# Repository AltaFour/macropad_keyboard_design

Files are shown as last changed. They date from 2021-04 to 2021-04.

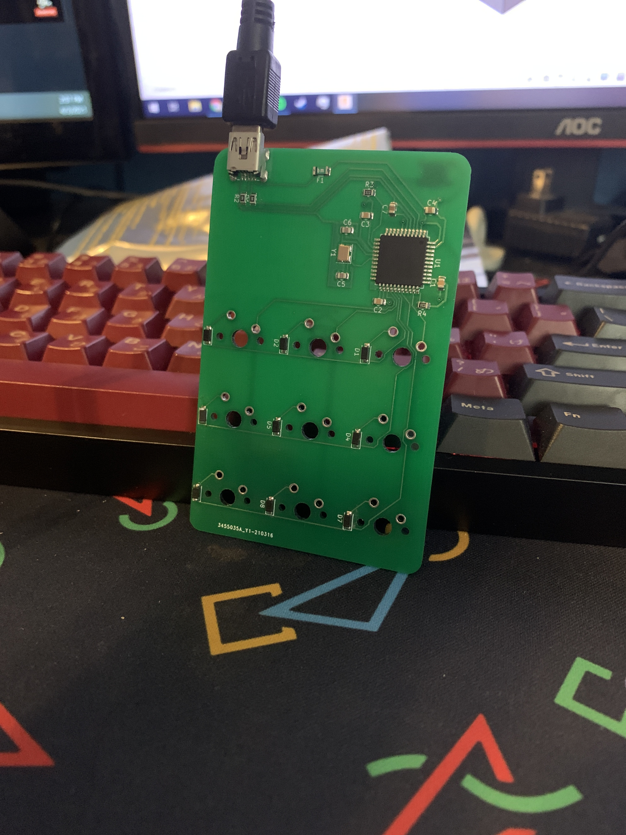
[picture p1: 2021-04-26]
Images/PCB-Assembled.JPG

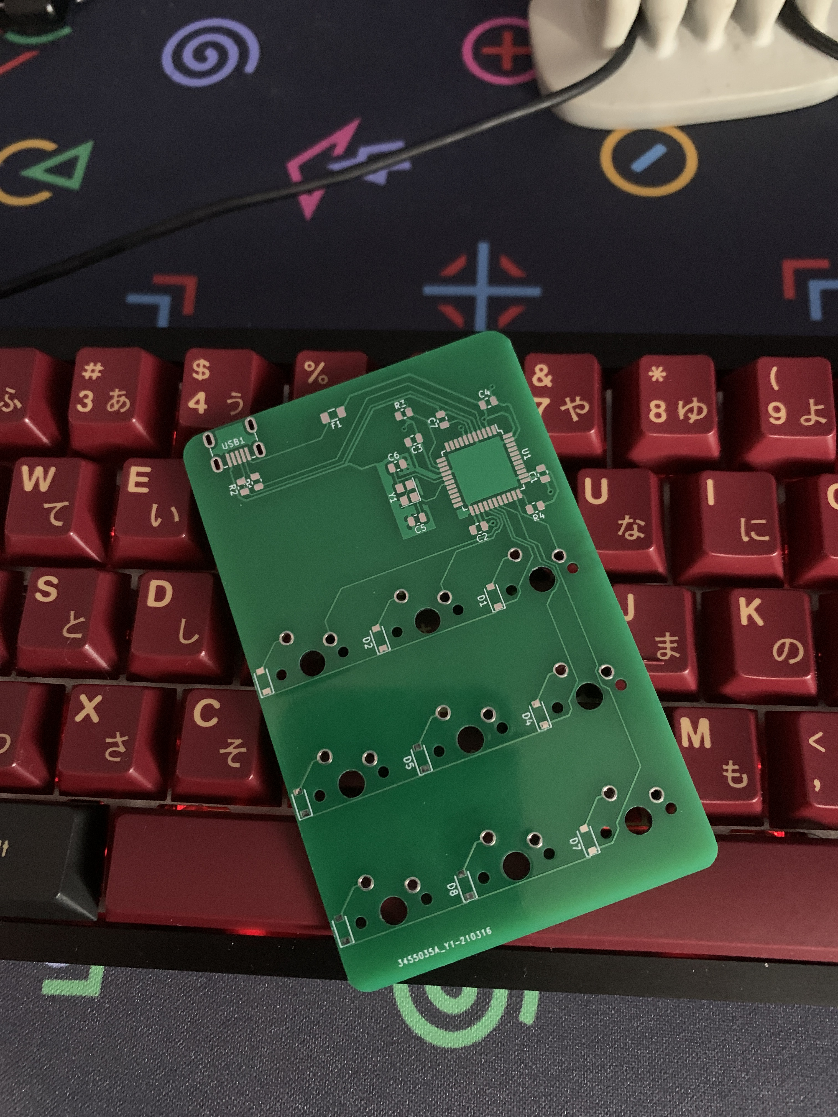
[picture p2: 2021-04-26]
Images/PCB-Back.JPG

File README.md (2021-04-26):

# macropad_keyboard_design
Software Used:
Autodesk Fusion 360 (Cad Software that is free for personal projects)
KiCad (Open Source PCB design software)
Github
Git

Manufacturing:
JLCPCB


This is the manufactured board without the components on it. I took this, solder paste and a aluminuim stencil and assembled the components on the board. I then put it in our toaster over and turned it up to full heat until all of the paste turned silver and metalic meaning that the connection was bridged.


This is a screenshot of the PCB design from KiCad which is a free open source pcb design software. I formatted this and sent it off to JLC PCB and they sent me the boards which are shown above.


This is a picture of the final product. I used SMD soldering to attach all the components. It has been flashed with QMK and works perfectly. I also designed a case that I am going to have 3d printed once we finish building our 3d printer(will attach pictures with case after).

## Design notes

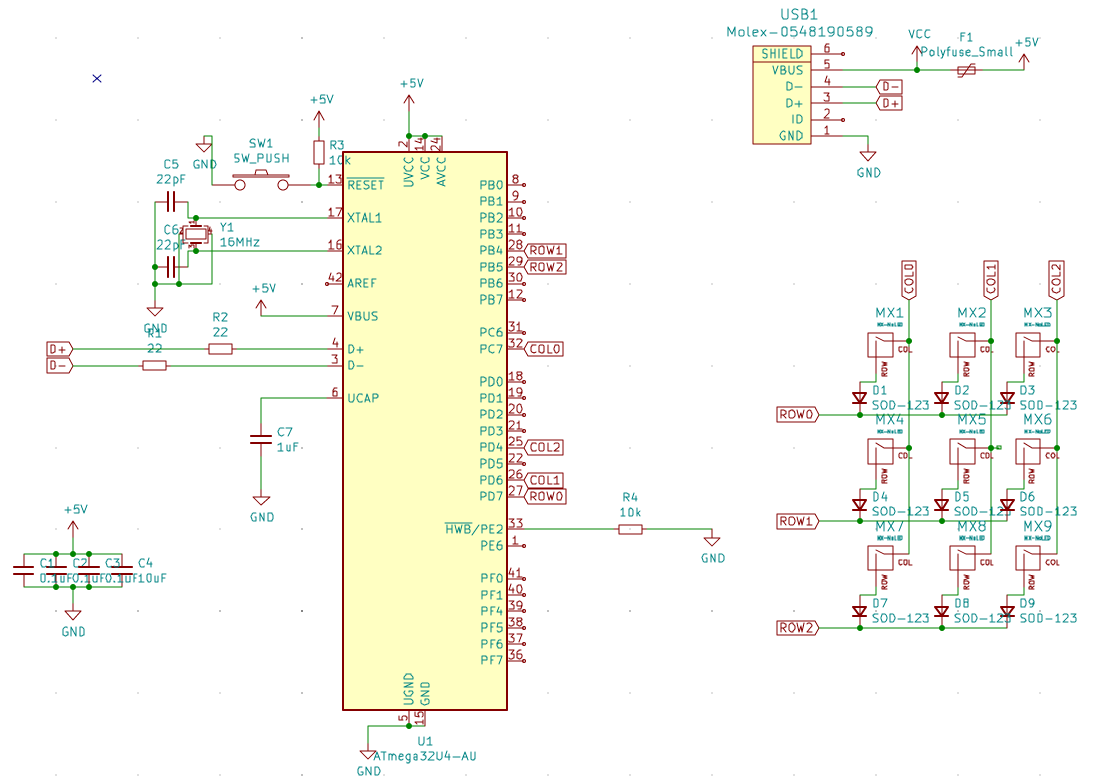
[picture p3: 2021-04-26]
Images/PCB-Schematic.png

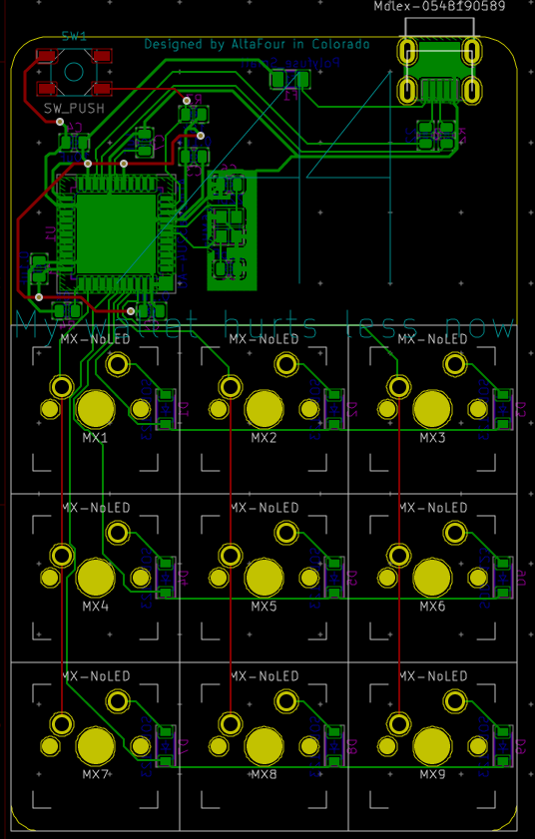
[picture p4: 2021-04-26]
Images/PCB-Layout.png

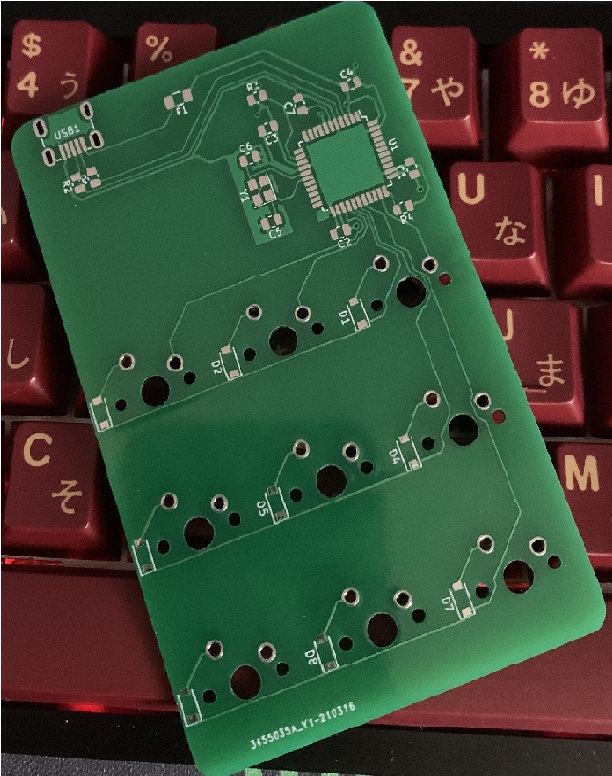
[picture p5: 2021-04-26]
Images/PCB-Back-Small.jpg

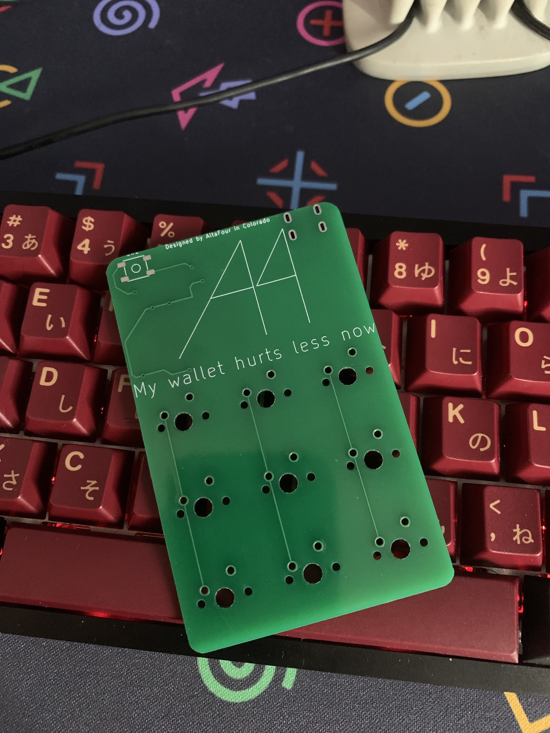
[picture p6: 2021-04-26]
Images/PCB-Front.JPG

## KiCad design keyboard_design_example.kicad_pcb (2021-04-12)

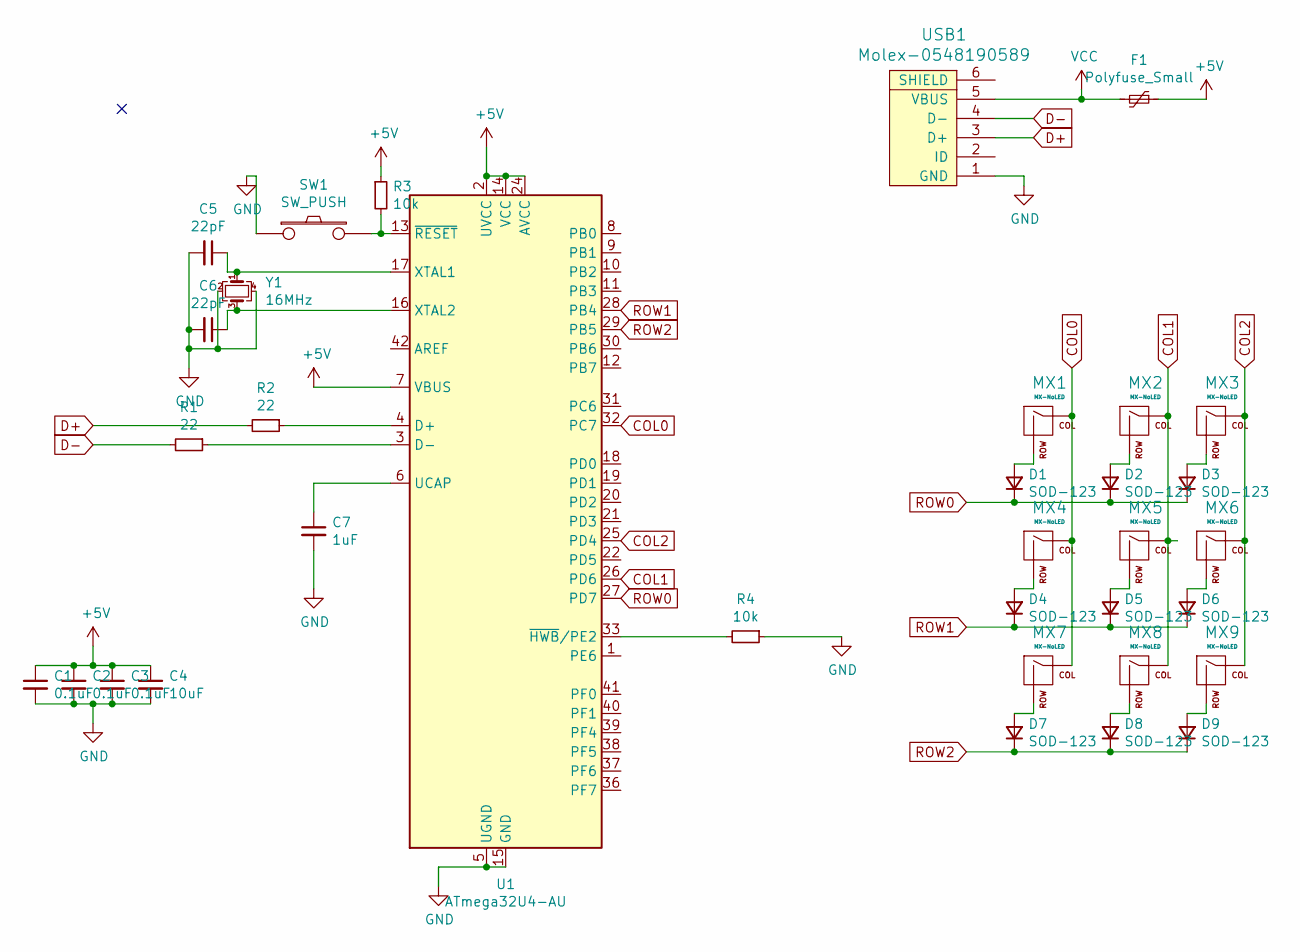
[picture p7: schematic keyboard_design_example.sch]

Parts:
C1, C2, C3: 0.1uF; C_0805_2012Metric
C4: 10uF; C_0805_2012Metric
C5, C6: 22pF; C_0805_2012Metric
C7: 1uF; C_0805_2012Metric
D1, D2, D3, D4, D5, D6, D7, D8, D9: SOD-123; D_SOD-123
F1: Polyfuse_Small; Fuse_1206_3216Metric
MX1, MX2, MX3, MX4, MX5, MX6, MX7, MX8, MX9: MX-NoLED; MXOnly-1U-NoLED
R1, R2: 22; R_0805_2012Metric
R3, R4: 10k; R_0805_2012Metric
SW1: SW_PUSH; SKQG-1155865
U1: ATmega32U4-AU; TQFP-44_10x10mm_P0.8mm
USB1: Molex-0548190589
Y1: 16MHz; Crystal_SMD_3225-4Pin_3.2x2.5mm

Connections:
+5V: C1.1, C2.1, C3.1, C4.1, F1.1, R3.1, U1.2 (UVCC), U1.7 (VBUS), U1.14 (VCC), U1.24 (AVCC), U1.34 (VCC), U1.44 (AVCC)
COL0: MX1.1 (COL), MX4.1 (COL), MX7.1 (COL), U1.32 (PC7)
COL1: MX2.1 (COL), MX5.1 (COL), MX8.1 (COL), U1.26 (PD6)
COL2: MX3.1 (COL), MX6.1 (COL), MX9.1 (COL), U1.25 (PD4)
D+: R2.2, USB1.3 (D+)
D-: R1.2, USB1.4 (D-)
GND: C1.2, C2.2, C3.2, C4.2, C5.2, C6.2, C7.2, R4.1, SW1.1, U1.5 (UGND), U1.15 (GND), U1.23 (GND), U1.35 (GND), U1.43 (GND), USB1.1 (GND), Y1.2, Y1.4
unnamed: C5.1, U1.17 (XTAL1), Y1.1
unnamed: C6.1, U1.16 (XTAL2), Y1.3
unnamed: C7.1, U1.6 (UCAP)
unnamed: D1.2 (A), MX1.2 (ROW)
unnamed: D2.2 (A), MX2.2 (ROW)
unnamed: D3.2 (A), MX3.2 (ROW)
unnamed: D4.2 (A), MX4.2 (ROW)
unnamed: D5.2 (A), MX5.2 (ROW)
unnamed: D6.2 (A), MX6.2 (ROW)
unnamed: D7.2 (A), MX7.2 (ROW)
unnamed: D8.2 (A), MX8.2 (ROW)
unnamed: D9.2 (A), MX9.2 (ROW)
unnamed: R1.1, U1.3 (D-)
unnamed: R2.1, U1.4 (D+)
unnamed: R3.2, SW1.2, U1.13 (~RESET)
unnamed: R4.2, U1.33 (~HWB~/PE2)
ROW0: D1.1 (K), D2.1 (K), D3.1 (K), U1.27 (PD7)
ROW1: D4.1 (K), D5.1 (K), D6.1 (K), U1.28 (PB4)
ROW2: D7.1 (K), D8.1 (K), D9.1 (K), U1.29 (PB5)
VCC: F1.2, USB1.5 (VBUS)

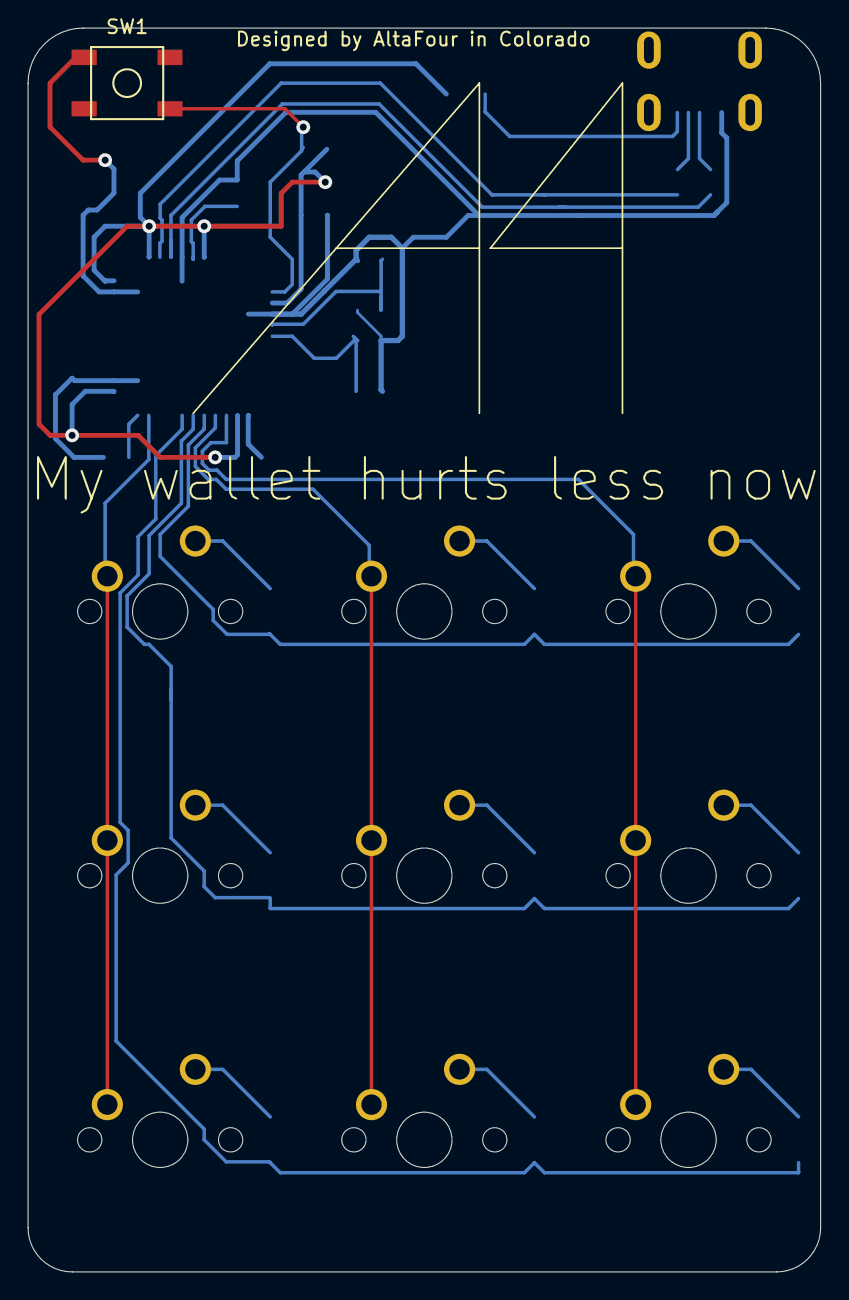
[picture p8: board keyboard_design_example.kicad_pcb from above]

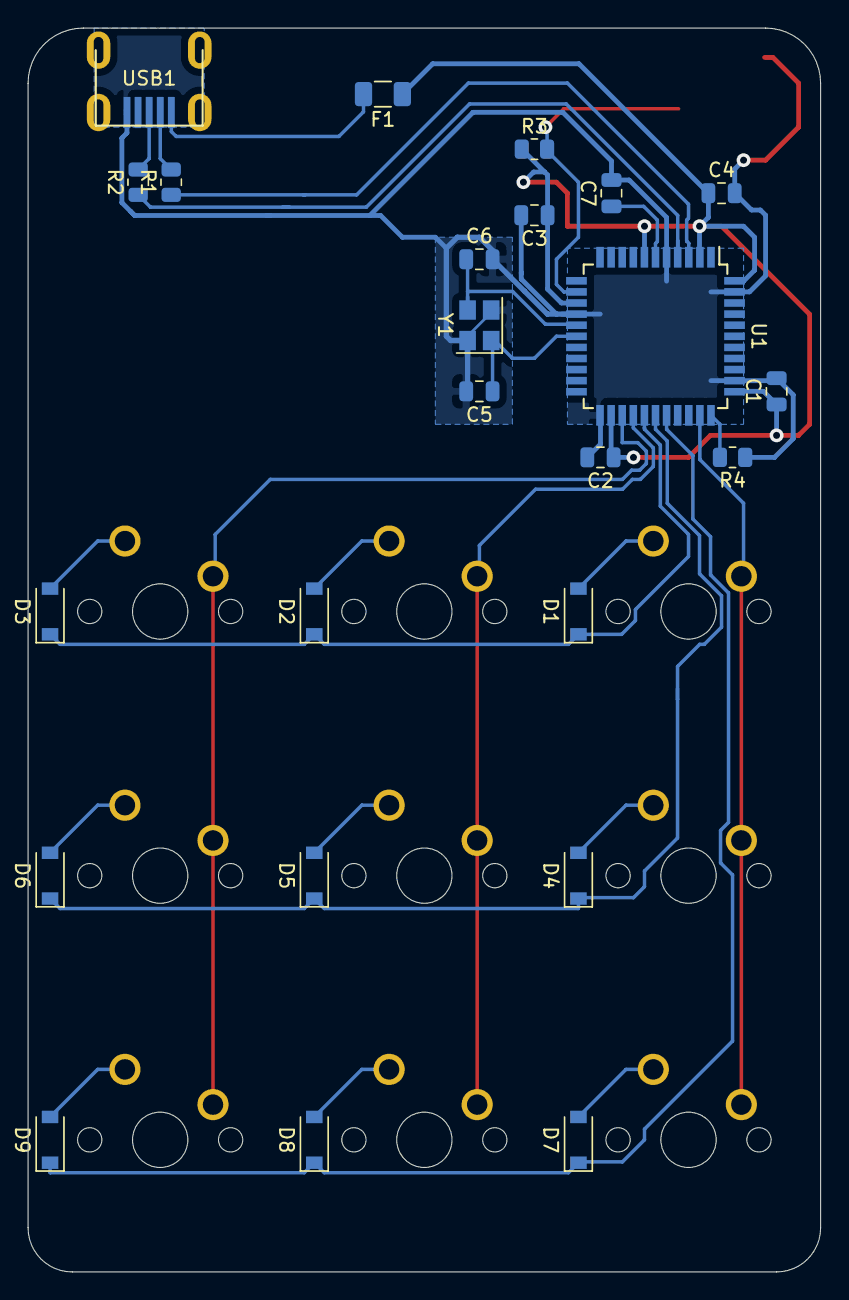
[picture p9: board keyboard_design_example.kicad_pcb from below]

Board: 2 copper layers, 57.1 x 89.7 mm, 34 parts (24 on the bottom side), 27 nets.

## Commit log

2021-02-07 Created Files
    Created initial files for the project.
    [keyboard_design_example.kicad_pcb, keyboard_design_example.sch]
2021-02-08 Added Footprint Libraries
    For fooprints such a switches and stuff when doing pcb.
2021-02-08 Updating
    Finished Schematic, moving onto pcb
2021-02-08 Update
    Started PCB Design
2021-02-10 Update and work
    [keyboard_design_example.kicad_pcb, keyboard_design_example.sch]
2021-02-15 2x2 bad 3x3 good
    Updated schematic for a 3x3 mx switch cluster.
    [keyboard_design_example.sch]
2021-02-15 Update
    Working on pcb organization
    [keyboard_design_example.kicad_pcb, keyboard_design_example.sch]
2021-02-15 Update
    stuff
    [keyboard_design_example.kicad_pcb]
2021-02-16 Update
    Did the crystal tracing POGGERS
    [keyboard_design_example.kicad_pcb]
2021-02-16 Update
    Did Stuff
    [keyboard_design_example.kicad_pcb]
2021-02-16 Finished
    WOOOO I think i finished. Might have to do some updates for fixes but its going good.
    [keyboard_design_example.kicad_pcb, keyboard_design_example.sch]
2021-02-16 Finished
    Did Some Edits. Its done. Seeking feedback
    [keyboard_design_example.kicad_pcb]
2021-02-16 Vertical MCU/usb
    Made the usb and MCU face vertically and rewired the switch matrix to the mcu
    [keyboard_design_example.kicad_pcb, keyboard_design_example.sch]
2021-02-16 Finishing touches
    yes
    [keyboard_design_example-B_Cu.gbr, keyboard_design_example-B_Mask.gbr, keyboard_design_example-B_Paste.gbr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]
2021-02-17 Update
    Still messing with it
    [keyboard_design_example-B_Cu.gbr, keyboard_design_example-B_Mask.gbr, keyboard_design_example-B_Paste.gbr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]
2021-02-22 Finished!!!
    I finally finished the pcb. It looks great and has my logo on it. Im gonna start my alice board project and try to get this one manufactured.
    [keyboard_design_example-B_Cu.gbr, keyboard_design_example-B_Mask.gbr, keyboard_design_example-B_Paste.gbr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]
2021-04-12 Firmware/Finish
    Created working firmware that works well and I have officially finished the project.
    [keyboard_design_example.kicad_pcb]
